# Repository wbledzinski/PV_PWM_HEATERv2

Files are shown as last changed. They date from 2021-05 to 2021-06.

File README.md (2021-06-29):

# PV_PWM_HEATERv2
photovoltaic MPPT electric heater controller for heat buffer

## MPPT PWM 400V DC 10A heater controller board

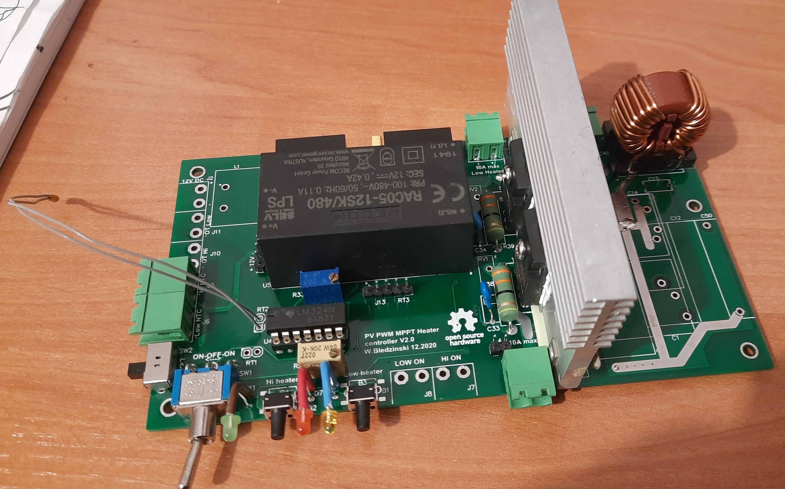
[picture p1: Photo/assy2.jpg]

Second version of controller

###  ◾ About this project
Project was developed to maximize energy transfer from 3,5kW solar array into heaters installed in 1000l heat buffer.
You can find similar systems already in market, ready to purchase but no one had power that I needed.
Below you can find schematic of the idea how to store small, medium and big amounts of heat generated by DC current from solar array.

###  ◾ Overall concept - how to store 50kWh of energy in form of heat and why
Some time ago I built heat buffer to collect and store heat from available heat sources. Basic concept was to store heat from buring coal or wood (furnace is more efficient working at full power and produces less air pollutants). Electric heaters were installed "just in case" of further development. Heat is used for heating whole house and tap water as well.

Using PV array to produce heat sounds as not particularly bright idea: during wintertime there is no enough sunny weather to produce reasonable amount of energy from PV array to heat whole building (I live at 50* latitude in Europe).
But summertime (autumn and spring usually as well) makes big difference. 5 people cannot use all heat produced by this system.
So during summertime I use generated heat to fill small pool (500liters) for kids - already with warm water, no waiting to warm-up, fresh and hot water in pool every day.
Also heat buffer is large enough that hot water stored from two sunny days lasts for next two days even if they are cloudy.
schematic of that system below

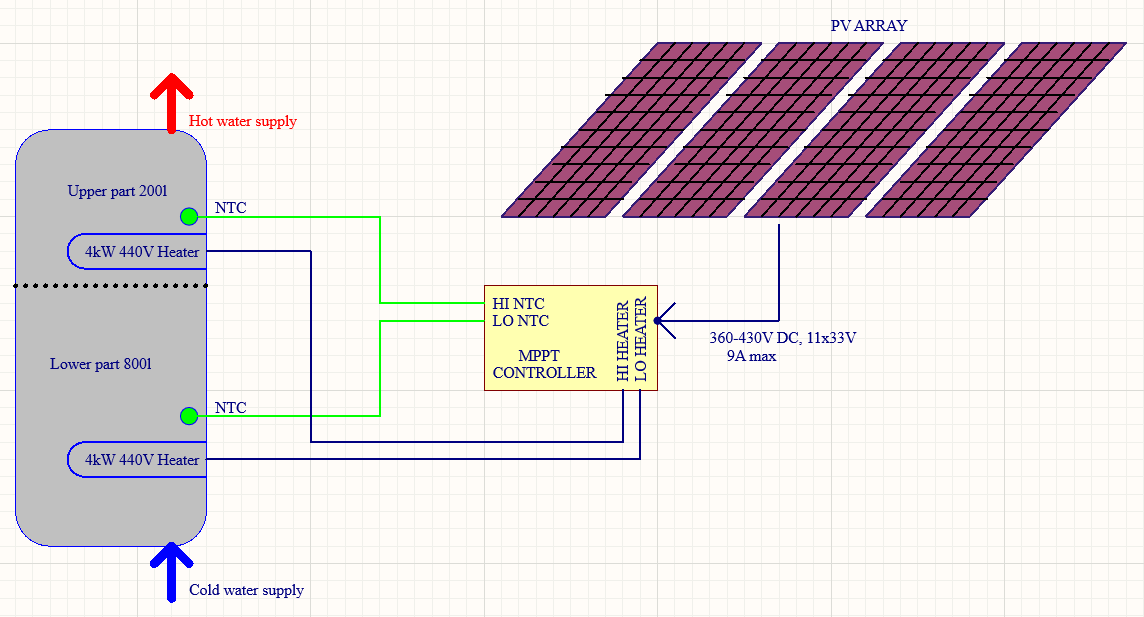
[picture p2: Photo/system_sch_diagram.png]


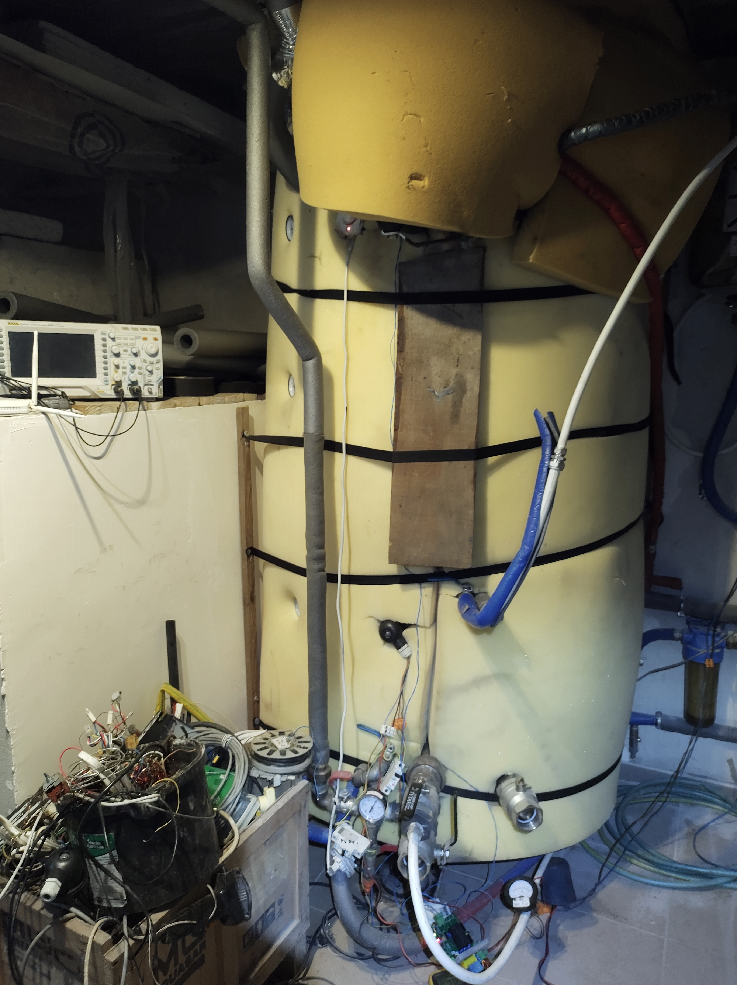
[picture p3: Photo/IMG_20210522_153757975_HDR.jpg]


real photo of heat buffer

###  ◾ Why I used two heaters
1. To make use of layered heat tank. If particular day is not excessively sunny then controller heats only upper part of the tank (200l of water).
2. if there is clear sky, long sunny day AND there is already hot water in upper part of the tank then controller stops using upper heater and drives only the lower heater
3. one heater (in form of serially connected two 230V 2kW heaters) can't put anough load to solar array. you need a bit more load so: in full sunshine upper heater works with 100% and lower just about 20% of possible load - only then you can mantain maximum power point (in my case somewhere ~360V DC).

###  ◾ MPPT Controller theory of operation ('MPPT' tracking)
Generally speaking you can't connect heaters directly as a load into solar array. Or at least you can, but you will loose lot of energy.
You can find lot of explanations why this is so.
So you have to track maximum power point of your solar array, controllers that can do that are called MPPT and they are usually very expensive (although there is reason for that). I thought that there is no sense of converting DC energy into AC energy to power simple electric heater. So after small research ([see sample project from youtube]( https://www.youtube.com/watch?v=ciyA7mSo7IY)) i decided to built my own controller board.

**Maximum-Power-Point-Tracking**
To be clear: controller doesn't follow power point of solar array, it follows voltage. I added temperature correction (about 10V) that depends on temperature of NTC.
In my case this NTC measures ambient temperature. To properly follow MPP of PV array you should measure temperature of PV array not ambient.
in my opinion this solution is good enough but not perfect.
Perfect solution should be based on microcontroller that calculates actual power not just voltage.

**General idea is to use RC circuit to oscillate around MPP of solar array.**
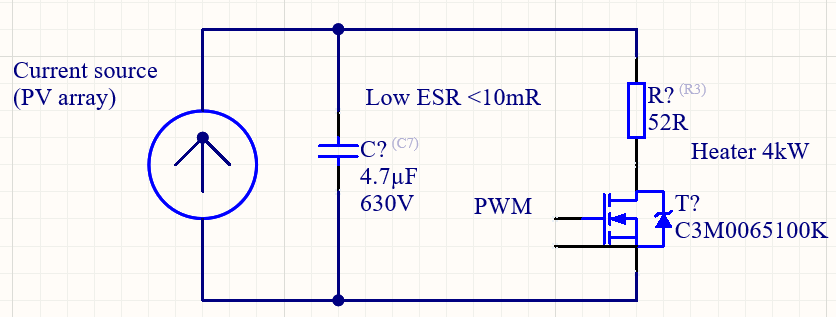
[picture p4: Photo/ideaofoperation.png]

It is basic idea of RC oscillator. The only difference is that PV array of that size produces 360VDC (disconnected even 440VDC) and almost 10A continuosly: RC oscillators usually have much less power.

So some simulations and futher research was needed.
Below you can find LTSpice simulation results for partially cloudy day (50% of PWM), just for simulation I set MPP at 330V.
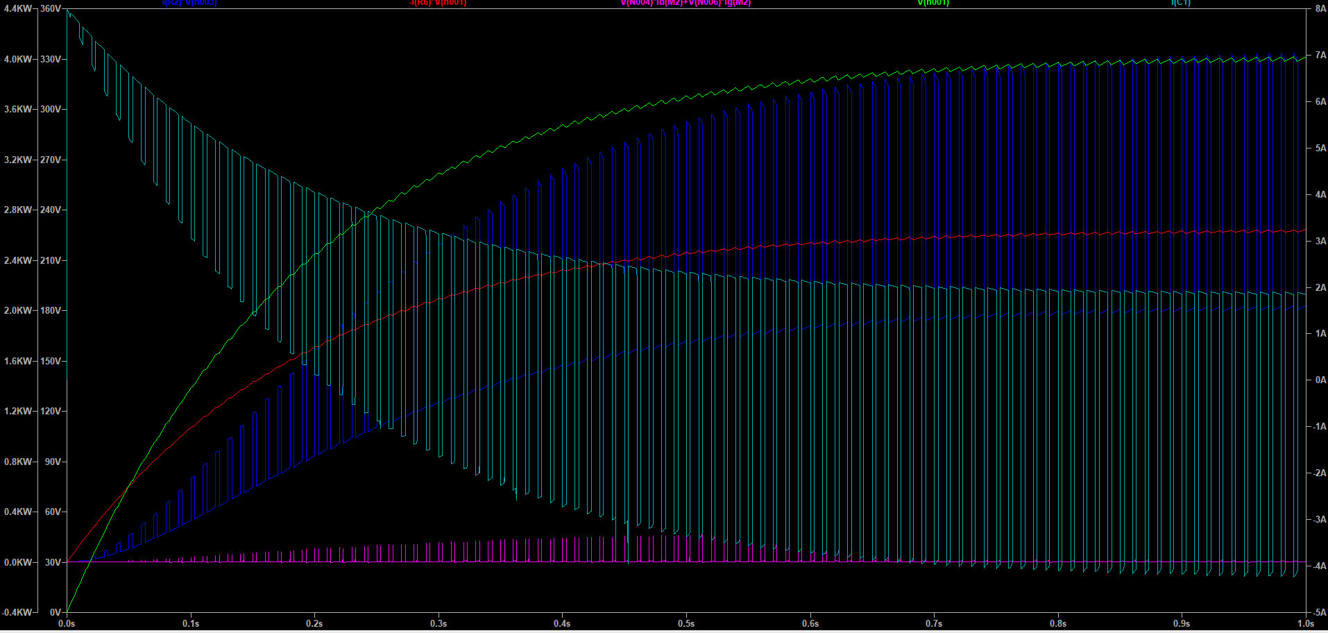
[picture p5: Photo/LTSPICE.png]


green curve shows oscillations around MPP at 360VDC (actually it is set by potentiometer on the board).
Hysteresis at 360V MPP was set to 5V.
transistor connects the load (heater) and main capacitor acts as short-term energy source.
Capacitor must withstand current of 10A so special low ESR capacitor is needed (4.7uF 630V DC 6mR from EPCOS)
transistor must be good as well: any inductance produces voltage spikes that doubles overall voltage between drain and source. And even driving mosfet with 100% PWM makes thing hard because 10A current produces conductivity loses.

Picture below shows Drain-Source voltage of SiC transistor (Infineon's IMZ120R030M1HXKSA1).
schema

###  ◾ Actual idea of operation for this controller
Critical components are big cap and two power transistors. I tested Infineons SiC parts IMZ120R030M1HXKSA1 and IMZ120R045M1XKSA1 toogether with EPCOS B32674D6475K000 4u7 and B32774D8126K000 12uF (don't be suprised, big cap value gives acoustic noise due to low frequency of operation BUT low frequency generates less commuting loses).
Actually I don't care about noise generated by caps, my controller and heat tank is installed in basement. So I've hosen lower frequency to decrease switching loses.

#### voltage set point

high priority heater (upper one) has circuit with mean voltage operation set point around 350VDC.

the lower priority heater has voltage set-point 10V higher ~360V DC.

In case of partial sun/low energy producing PV array (due to low sun early in the morning, or due to cluds) controller uses only high pririty heater (upper in the heat buffer) and operates around 350V DC.

When PV array produces more than 2,5kW of power one heater (~52ohm) cann't operate at MPP for PV array - voltage raises even to 380VDC. No problem for the heater but operating at that high voltage is out of MPP for my arrray.
So there comes into action second heater with second (10V higher) voltage set-point:
upper heater is driven 100% PWM, and second (physically lower in heat buffer) heater is driven with PWM that enables PV to operate at 360V DC.
PV array can then operate at voltage point close to MPP.

if there is already hot water in the tank AND sunny weather continues the controller stops driving both heaters and gives signal thru optocouplers: you can use that to control classic grid inverter to generate electricity and return that to the grid. But heaters have priority in that case and energy can be sent to grid only when there is no need for generatin more heat.

###  ◾ Safety of electric and hydraulic systems
there is no strict SIL biult-in in that controller. I would recommend some double security to preven fire (due to overheating of electronics itself) or to prefent pressure biuldup in heater tank (in case of NTC failure).
My system has only one level of safety for every critical component.
1. thermostat for transistor heatsink - over 100C it disconnects voltage sensing - controller stops operation
2. 2x NTC at heat buffer - to preven overheating/boiling water. But if NTC fails due to internal malfunction OR due to lack of sufficient thermal connection to tank OR if there is short on power transistor *there is no other security measure to preven overheating
3. to prevent pressure build-up (in case of NTC failure or transistor malfunction ) that tank itself has an overflow port - it allows to escape if there is any excessive prese, no matter the cause: from excessive water level or from steam
4. to prevent any burn due to very hot tap vater I installed hydraulic thermostat valve at buffer output, it is set to 55C
5. to prevent any bacteria to growth you can't store 1000l of tap water. Buffer has built-in heat exchanger in form of spiral copper pipe (copper itself is bacteriostatic), 20mm diameter, 50m long. Heat exchanger capacity is about 10liters. 1000l of water accumulates heat and never will be used for consumtion directly in any form.

temperature limits for heaters are set (with hysteresis):
testing original (designed) resistor values:
switch position Low Temperature

NTC L: 1,5k - 1,9k	(73*C-66*C)

NTC H: 3,1k-4,0k	(53*C-47*C)

switch position High Temperature

NTC L: 1,2k-1,3k	(80*C-76*C)

NTC H: 1,8k-2,1k	(68*C-59*C)

###  ◾ Main components
Sorry for choosen language but this is the exact part number that I used.
heater
https://www.egniazdka.pl/grzalka-do-bojlera-z-kolpakiem-eliko-grbk-3x2000w-u-64-p-1829.html
low ESR capacitor
https://pl.farnell.com/epcos/b32674d6475k000/cap-4-7-f-630v-10-pp/dp/2728560
SiC transistor
https://pl.farnell.com/infineon/imz120r030m1hxksa1/mosfet-n-ch-1-2kv-56a-175deg-c/dp/3223684
DCDC converter
https://pl.farnell.com/recom-power/rac10-12sk-277/power-supply-ac-dc-12v-0-84a/dp/2822840

### ◾ Similar solution
https://www.ebay.de/itm/Hezspirale-Heizelement-Heizstab-6000-W-3x2000W-230-V-Abdeckung-/221984855525
here similar solution, but with only one channel , smaller voltage (for smaller PV array)

###  ◾ BOM cost
I had to build two versions + during testing I burned one transistor (due to DC arc) so this was not completely cheap project.
but properly assembled one piece of that board should cost you about:
* PCB JLCPCB $20
* main transistors, capacitor, DCDC converter other major components about $100

###  ◾ Assembly
Only one uncommon thing about assembly. All SMD components were soldered using soldering paste and "T962 Infrared SMD BGA IC Heater". smallest component is of 0603 size and I tested 3D printed stencil - it works pretty good for components of that size. Smallest IC is SOT23-5 and there was no need for improving soldering point manually.
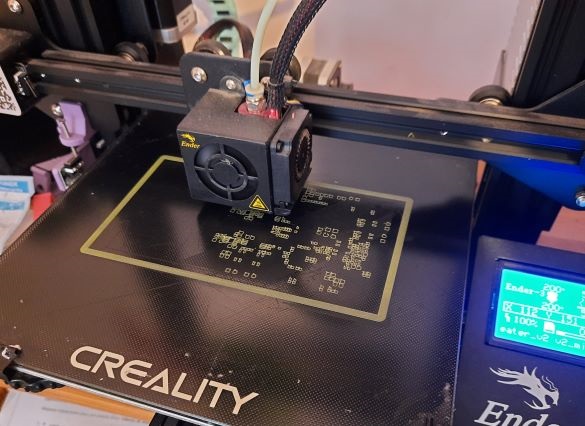
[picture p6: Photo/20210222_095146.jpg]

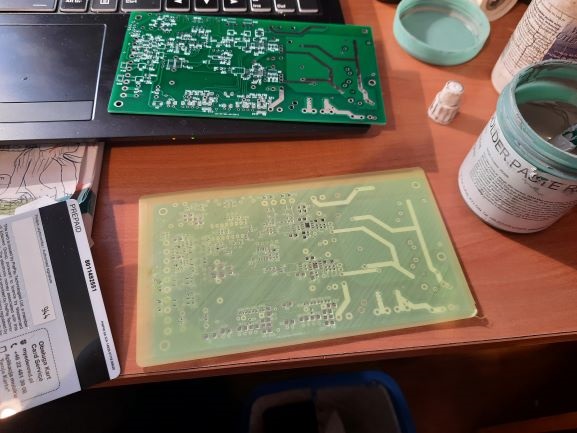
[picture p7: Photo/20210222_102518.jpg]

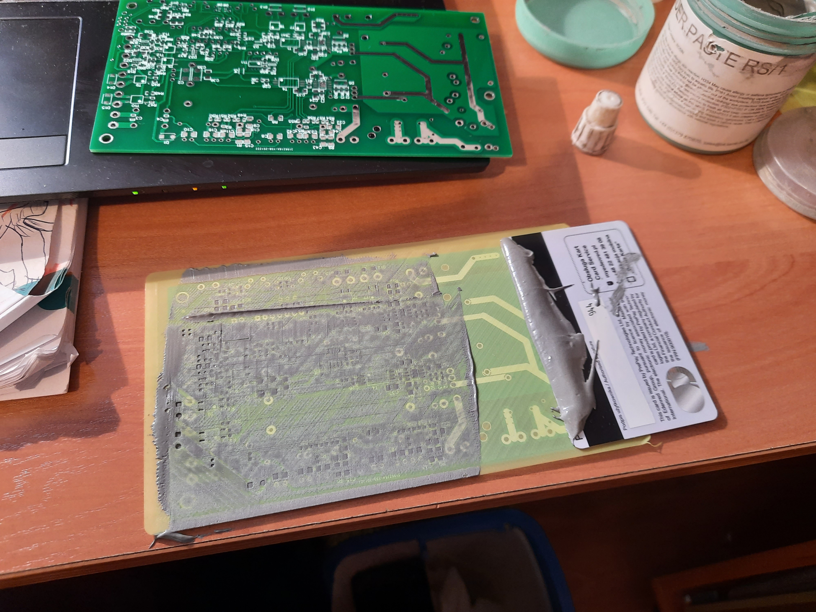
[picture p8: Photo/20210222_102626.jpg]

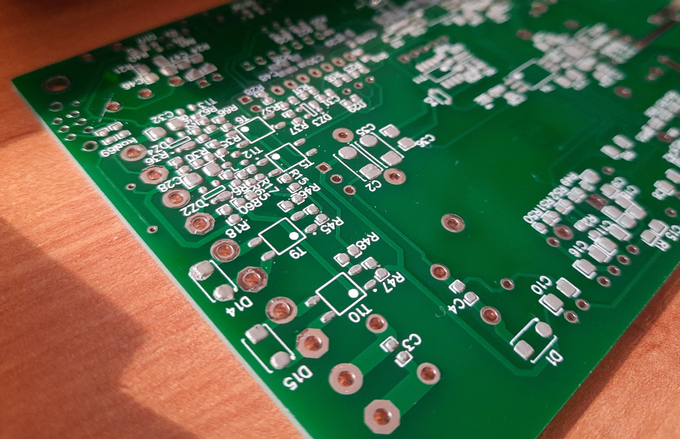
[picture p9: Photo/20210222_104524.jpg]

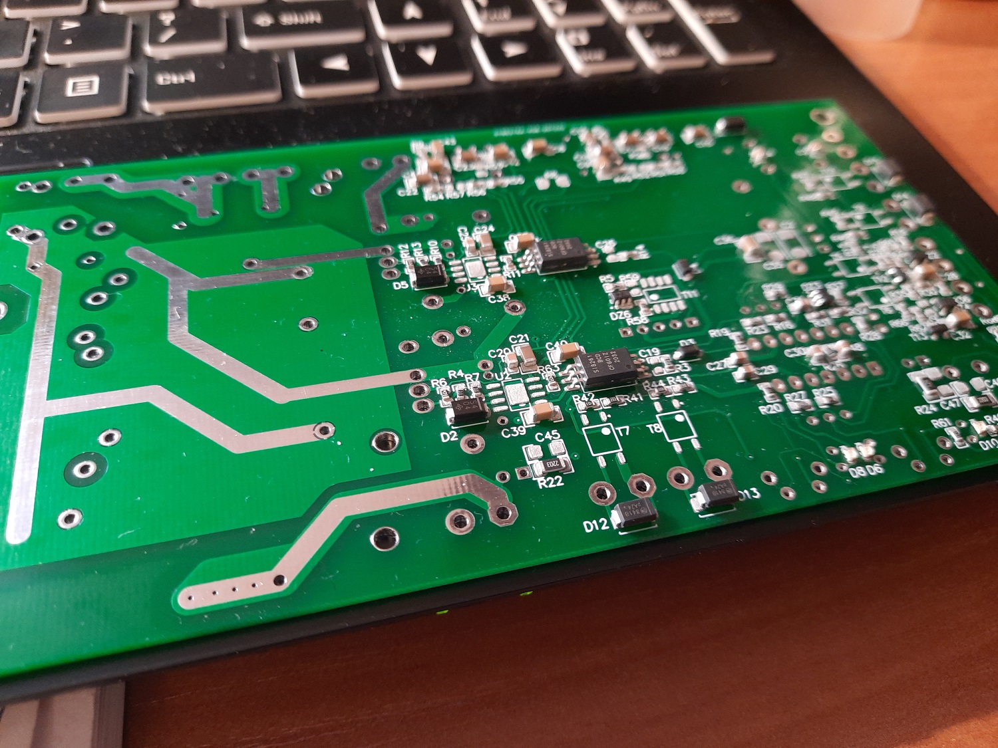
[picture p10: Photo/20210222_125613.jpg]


###  ◾ Launching
Durnig launching you have to set voltage operating points near maximum power point of your PV array - by setting both potentiometers.
I've checked temperatures during operation, picture below shows board temperatures during hot sunny day, current from PV array ~8A, PV temperature ~40degC.
Power transistors (natural convection) has ~50degC.
During sunny but cold day when PV array is cold (say 0degC) current reaches even 11A (more than nominal specified by manufacturer of my panels (320W longi).

Actually I had no issues during launching whatsoever.

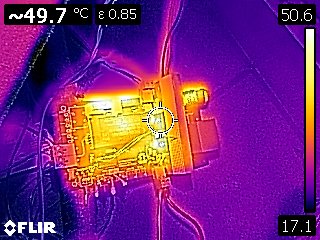
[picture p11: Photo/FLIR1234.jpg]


the only damage to first version (100% my fault, just don't short drain and source during operation, it will create an arc)

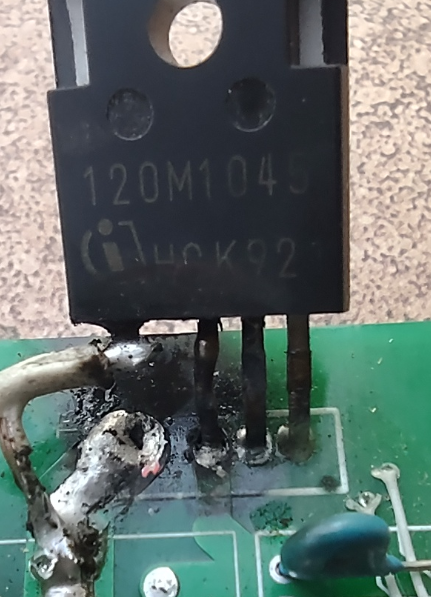
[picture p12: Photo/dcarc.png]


###  ◾ Summary
I hope you enjoy this project. I'm sure that furher development should use microcontroller to properly control MPPT of solar array.
For me most important part is that I developed high voltage power stage of that controller, further development should consider change of SiC driver for something more covienient, e.g. NCP51705; move from op-amp logic for microcontroller. It seems less stresfull during launch (leaving that installation for a week without supervision really maked me stressed, I imagined firefighters in place several times, even hearing nearby sirene made me anxious).
As for now it works without any flaws.

Do not hesitate to reach me in case of any questions,
br,

Wojtek

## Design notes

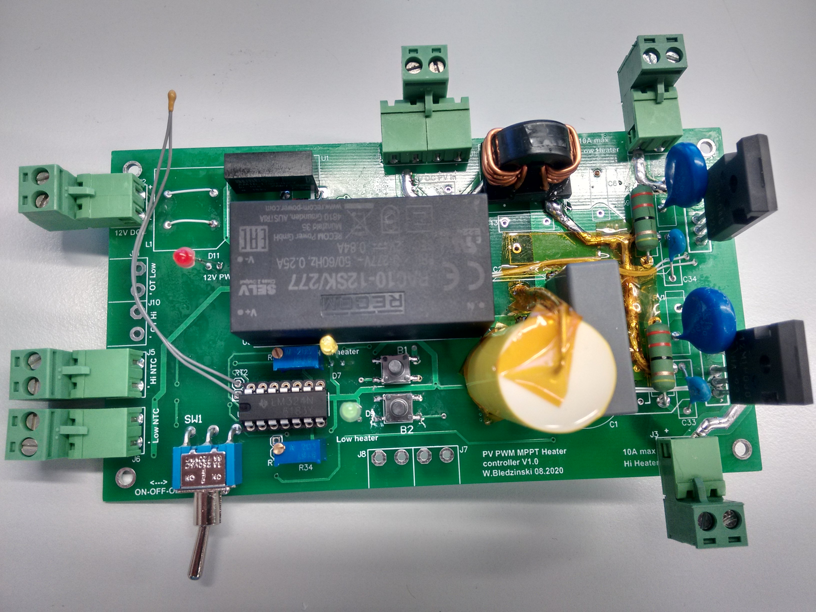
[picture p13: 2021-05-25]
Photo/assy1.jpg

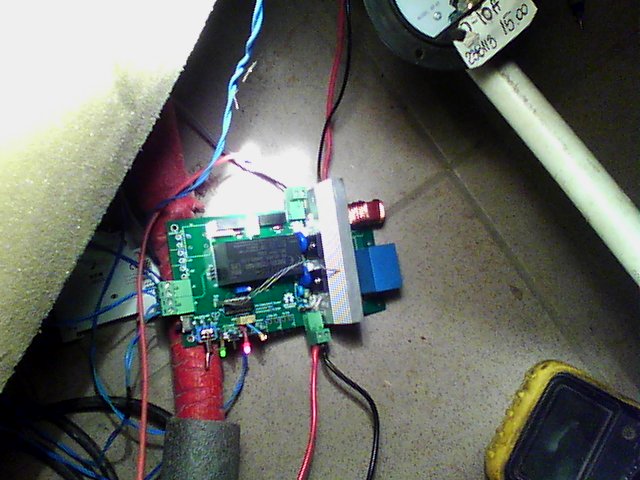
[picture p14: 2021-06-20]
Photo/FLIR1235.jpg

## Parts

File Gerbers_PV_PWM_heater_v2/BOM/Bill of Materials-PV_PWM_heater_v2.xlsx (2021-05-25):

Comment | Description | Designator | Footprint | LibRef | LogicalDesignator | Manufacturer | Manufacturer 1 | Manufacturer 2 | Manufacturer Part Number | Manufacturer Part Number 1 | Manufacturer Part Number 2 | PartType | Price10 | Price1k | Pricing | Quantity | Supplier | Supplier 1 | Supplier 2 | Supplier Currency 1 | Supplier Currency 2 | Supplier Order Qty 1 | Supplier Order Qty 2 | Supplier Part Number | Supplier Part Number 1 | Supplier Part Number 2 | Supplier Stock 1 | Supplier Stock 2 | Supplier Subtotal 1 | Supplier Subtotal 2 | Supplier Unit Price 1 | Supplier Unit Price 2 | Value | Layer
SW_TACTSWITCH6x6 | SE PUSHBUTTON | B1, B2 | SW_TACT6x6 | SW_TACTSWITCH6x6 | B1, B2 | ITT C&K | Loading... |  | PTS645SK50SMTR92LFS | Loading... |  | SW_TACTSWITCH6x6 |  |  |  | 2 |  | TME |  | Loading... |  |  |  |  | PTS645SK50SMTR92 |  |  |  |  |  | $0.1402 |  |  | Top
SW_TACTSWITCH6x6_RA_THT | SE PUSHBUTTON | B3, B4 | SW_TACT6x6_RA | SW_TACTSWITCH6x6_RA_THT | B3, B4 | TE | Loading... |  | 1-1825027-1 | Loading... |  | SW_TACTSWITCH6x6_RA_THT |  |  |  | 2 |  | TME |  | Loading... |  |  |  |  | 1-1825027-1 |  |  |  |  |  | $0.1402 |  |  | Top
12u/700VAC | poliester capacitor THT | C1, C12, C50 | CAP_THT27.5mm | CAP_B_12u_700_THT | C1, C12, C50 | EPCOS |  |  | B32774D8126K000 |  |  | 12u/700VAC | 8 | 6 |  | 3 | TME | FARNELL |  |  |  |  |  |  |  |  |  |  |  |  |  |  | 12u/700VAC | Top
47u/16 | ESR 1.2R 10VDC at 125stC | C2, C35 | TAJC | CAP_E_47u_16_TAJC | C2, C35 | KEMET | Loading... |  | T491C476K016AT | Loading... |  | 47u/16 | 0.4 | 0.3 |  | 2 | TME | Farnell |  | Loading... |  |  |  | T491C476K016AT | 1457486 |  |  |  |  |  | Loading... |  | 47u/16 | Bottom
100n/50 | X7R chip capacitor | C3, C4, C20, C25, C27, C29, C30, C31, C48 | CAP_0603 | CAP_B_100n_50_0603_X7R | C3, C4, C20, C25, C27, C29, C30, C31, C48 | SAMSUNG |  |  | CL10B104KB8NNNC |  |  | 100n/50 | 0.1 | 0.006 |  | 9 | TME |  |  |  |  |  |  | CL10B104KB8NNNC |  |  |  |  |  |  |  |  | 100n/50 | Bottom
1u/850VDC | poliester capacitor THT, esr 5mR, 9A/140A pk | C5 | CAP_AXIAL50X20mm | CAP_B_1u_850_THT | C5 | KEMET | Loading... |  | C4GAMUC4100AA1J | Loading... |  | 1u/850VDC | 3.8 | 2.44 |  | 1 | TME | FARNELL |  | Loading... |  |  |  | C4GAMUC4100AA1J | 2808972 |  |  |  |  |  | Loading... |  | 1u/850VDC | Top
3u3/600VDC | poliester capacitor THT, esr 2.4mR, 25A/342A pk; 350VAC | C6 | CAP_THT27.5X22mm | CAP_B_3u3_600_THT | C6 | KEMET | Loading... |  | C4ATHBW4330A3GJ | Loading... |  | 3u3/600VDC | 6.18 | 4.02 |  | 1 | TME | FARNELL |  | Loading... |  |  |  | C4ATHBW4330A3GJ | 2664828 |  |  |  |  |  | Loading... |  | 3u3/600VDC | Top
2n2/250VAC X1,Y2 | poliester capacitor THT X1 Y2, Y5V | C7, C13, C49 | CAP_THT7.5mm | CAP_B_2n2_250_X1Y2_THT | C7, C13, C49 |  |  |  | CY2V-2N2 |  |  | 2n2/250VAC X1,Y2 | 0.3 | 0.25 |  | 3 | TME |  |  |  |  |  |  | CY2V-2N2 |  |  |  |  |  |  |  |  | 2n2/250VAC X1,Y2 | Top
1u/50 | X7R chip capacitor | C8, C9, C10, C11, C15, C16, C18, C21, C22, C23, C24, C28, C32, C36, C37, C38, C39, C40, C42, C43, C44 | CAP_1206 | CAP_B_1u_50_1206_X7R | C8, C9, C10, C11, C15, C16, C18, C21, C22, C23, C24, C28, C32, C36, C37, C38, C39, C40, C42, C43, C44 | TDK | Loading... |  | C3216X7R1H105K160AB | Loading... |  | 1u/50 | 0.24 | 0.044 |  | 21 | TME | FARNELL |  | Loading... |  |  |  | 12065C105KAT2A | 1857302 |  |  |  |  |  | Loading... |  | 1u/50 | Bottom
5u6/500VDC | poliester capacitor THT, esr 13mR, | C14 | CAP_THT27.5X11mm | CAP_B_5u6_500_THT | C14 | KEMET | Loading... |  | C4AQLBU4560A1WK | Loading... |  | 5u6/500VDC | 2 | 0.8 |  | 1 | TME | FARNELL |  | Loading... |  |  |  | C4AQLBU4560A1WK | 2846425 |  |  |  |  |  | Loading... |  | 5u6/500VDC | Top
2n2/250VAC | poliester capacitor THT Y2 | C17, C41 | CAP_THT10mm | CAP_B_2n2_250_THT | C17, C41 | WIMA |  |  | MPY20W1220FA00MSSD |  |  | 2n2/250VAC | 0.3 | 0.25 |  | 2 | TME |  |  |  |  |  |  | MP3-Y2-2N2 |  |  |  |  |  |  |  |  | 2n2/250VAC | Top
DNP | X7R chip capacitor | C19, C26 | CAP_0603 | CAP_B_100n_50_0603_X7R | C19, C26 | SAMSUNG |  |  | CL10B104KB8NNNC |  |  | DNP | 0.1 | 0.006 |  | 2 | TME |  |  |  |  |  |  | CL10B104KB8NNNC |  |  |  |  |  |  |  |  | 100n/50 | Bottom
220p | poliester capacitor THT X1 Y2, Y5V | C33, C34 | CAP_THT7.5mm | CAP_B_2n2_250_X1Y2_THT | C33, C34 |  |  |  | CY2V-2N2 |  |  | 220p | 0.3 | 0.25 |  | 2 | TME |  |  |  |  |  |  | CY2V-2N2 |  |  |  |  |  |  |  |  | 2n2/250VAC X1,Y2 | Top
1n/200V | C0G chip capacitor | C45, C46, C47 | CAP_1206 | CAP_B_100n_50_1206_C0G | C45, C46, C47 | TDK | Loading... |  | CGA5L2C0G1H104J160AA | Loading... |  | 1n/200V | 0.7 | 0.16 |  | 3 | FARNELL | FARNELL |  | Loading... |  |  |  | 2211074 | 2211074 |  |  |  |  |  | Loading... |  | 1n/200V | Bottom
Shottky 2A/20V | Shottky Diode 0,5V @ 2A SMA 200pF | D1 | SMA_DO-214AC | D_2A_20_B220A | D1 | DIODES | Loading... |  | B220A-13-F | Loading... |  | Shottky 2A/20V | 0.15 | 0.06 |  | 1 | AVNET | FARNELL |  | Loading... |  |  |  | B220-13-F | 1858604 |  |  |  |  |  | Loading... |  | Shottky 2A/20V | Bottom
SS14-E3/61T |  | D2, D5 | SMA_DO-214AC | D_SS14 | D2, D5 | Vishay Semiconductors | Loading... |  | SS14-E3/61T | Loading... |  | SS14-E3/61T |  |  |  | 2 |  | TME |  | Loading... |  |  |  |  | SS14-E3/61T |  |  |  |  |  | $0.26376 |  |  | Bottom
Shottky 0.5A/30V MBR0530T1G | Shottky Diode trr 4ns 0,43V @ 0.5A 0.37V@0.1A | D3, D4 | SOD_123 | D_0.5A_30_MBR0530T1G | D3, D4 | ON | Loading... |  | MBR0530T1G | Loading... |  | Shottky 0.5A/30V MBR0530T1G | 0.38 | 0.06 |  | 2 | TME | FARNELL |  | Loading... |  |  |  | MBR0530T1G | 1431036 |  |  |  |  |  | Loading... |  | Shottky 0.5A/30V MBR0530T1G | Bottom
Green LED KP-1608SGC | Diode LED SMD 2.2V @ 20mA 15mcd | D6, D8, D10 | LED_0603_GREEN | D_LED_0603_GREEN | D6, D8, D10 | KINGBRIGHT | Loading... |  | KP-1608SGC | Loading... |  | Green LED KP-1608SGC | 0.05 | 0.03 |  | 3 | TME | Farnell |  | Loading... |  |  |  | KP-1608SGC | 8529833 |  |  |  |  |  | Loading... |  | Green LED KP-1608SGC | Bottom
Red LED 3mm THT | Diode LED THT | D7, D9, D11 | LED_3MM | D_LED3_THT_RED | D7, D9, D11 | KINGBRIGHT | Loading... |  | L-934SRC-E | Loading... |  | Red LED 3mm THT | 0.12 | 0.1 |  | 3 | TME | Farnell |  | Loading... |  |  |  | L-934SRC/E | 1142524 |  |  |  |  |  | Loading... |  | Red LED 3mm THT | Top
39 | transil jednostronny | D12, D13, D14, D15 | SMA_DO-214AC | D_TR_UNI_SMA6TY_39V | D12, D13, D14, D15 | STM | Loading... |  | SMA6T39AY | Loading... |  | 39 | 1 | 0.4 |  | 4 | ARROW | Digi-key |  | Loading... |  |  |  | SMA6T39AY | 497-10949-2-ND |  |  |  |  |  | Loading... |  | Transil_U_600W | Bottom
3V 1W |  | DZ1, DZ5 | D_DO-15_DO-204AC | D_1W_20_ZENER | DZ1, DZ5 |  | Loading... |  |  | Loading... |  | 3V 1W | 0.08 | 0.04 |  | 2 | TME | TME |  | Loading... |  |  |  | 1.3W-3V | 1.3W-3V |  |  |  |  |  | Loading... |  | 3V 1W | Top
TS431 0,5% 1.24V | 0,5% 1.24V vref | DZ2, DZ3, DZ4, DZ6 | SOT23_5_DBV_R-PDSO-G5 | D_TS431BILT | DZ2, DZ3, DZ4, DZ6 | STMicroelectronics | Supplier disabled |  | TS431BILT | Supplier disabled |  | TS431 0,5% 1.24V |  |  | 6000=0.2339, 12000=0.2229, 18000=0.2129, 30000=0.2029, 60000=0.1989 (USD) | 4 | TME | Avnet |  | Supplier disabled |  |  |  |  | TS431BILT |  |  |  |  |  | Supplier disabled |  | TS431 0,5% 1.24V | Bottom
5.08 TB H | THT 5,08mm, WE 691312510002, NINIGI TBG-5-KB-2P/GN, MLX 395320002 | J1, J2, J3, J4, J5, J6, J7, J8, J9, J10, J11 | CON_1x2_5.08TBRA | CON_1x2_TB_5.08H | J1, J2, J3, J4, J5, J6, J7, J8, J9, J10, J11 | Molex | Loading... (https://octopart-clicks.com/click/altium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) | Loading... (https://octopart-clicks.com/click/altium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) | 39532-0002 | Loading... (https://octopart-clicks.com/click/altium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) | Loading... (https://octopart-clicks.com/click/altium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) | 5.08 TB H |  |  |  | 11 |  | Mouser | TME | Loading... | Loading... |  |  |  | 710-691312510002 (https://octopart-clicks.com/click/altium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) | TBG-5-KB-2P/GN (https://octopart-clicks.com/click/altium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) |  |  |  |  | $0.8421 |  |  | Top
1x3p 2.54mm GP | THT 2,54 goldpin | J12, J13 | CON_PIN1x3_THT | CON_1x3_GP_THT | J12, J13 | TME | Loading... |  | ZL201-03G | Loading... |  | 1x3p 2.54mm GP | 0.15 | 0.1 |  | 2 | TME | digi-key |  | Loading... |  |  |  | ZL201-03G | WM8073-ND |  |  |  |  |  | Loading... |  | 1x3p 2.54mm GP | Top
1x2p 2.54mm GP | THT 2,54 goldpin | J14 | CON_PIN1x2_THT | CON_1x2_GP_THT | J14 | TME | Loading... |  | ZL201-02G | Loading... |  | 1x2p 2.54mm GP | 0.15 | 0.1 |  | 1 | TME | digi-key |  | Loading... |  |  |  | ZL201-02G | WM8072-ND |  |  |  |  |  | Loading... |  | 1x2p 2.54mm GP | Top
2,2mH 4A 744823422 | 2x2,2mH 40dB 1MHz 4A 250VAC Rdc=2x0,03 SRF1MHz | L1, L2 | IND_WE-CMB-M | IND_WE-CMB_2.2mH_4A_THT | L1, L2 | WE | Loading... |  | 744823422 | Loading... |  | 2,2mH 4A 744823422 | 5 | 4.5 |  | 2 | RS-Components | Digi-Key |  | Loading... |  |  |  | 489-0273 | 732-1445-ND |  |  |  |  |  | Loading... |  | 2,2mH 4A 744823422 | Top
2,2mH 4A 744824101 | 2x2,2mH 30dB 1MHz 10A 250VAC Rdc=2x0,007 SRF1MHz | L3 | IND_WE-CMB-l | IND_WE-CMB_2.2mH_10A_THT | L3 | WE | Loading... |  | 744824101 | Loading... |  | 2,2mH 4A 744824101 | 5 | 4.5 |  | 1 | RS-Components | Digi-Key |  | Loading... |  |  |  |  | 732-1449-ND |  |  |  |  |  | Loading... |  | 2,2mH 4A 744824101 | Top
2k | Resistor 1206 5% 0,25W | R1, R9 | RES_1206 | RES_510R_5p_1206 | R1, R9 | YAGEO | Loading... |  | RC1206JR-07510R | Loading... |  | 2k | 0.009 | 0.004 |  | 2 | TME | Farnell |  | Loading... |  |  |  | RC1206JR-07510R | 2057829 |  |  |  |  |  | Loading... |  | 510R 5% | Bottom
DNP | 0603 ,1W, 0603 ,1W, 0603 ,1W, 0603 ,1W, Resistor 0603 5% 0,1W, Resistor 0603 5% 0,1W, Resistor 0603 5% 0,1W | R2, R52, R53, R57, R59, R60, R62 | RES_0603 | RES_0R_5p_0603, RES_0R_5p_0603, RES_0R_5p_0603, RES_0R_5p_0603, RES_3k_5p_0603, RES_3k_5p_0603, RES_3k_5p_0603 | R2, R52, R53, R57, R59, R60, R62 | YAGEO | Loading... |  | RC0603JR-070RL, RC0603JR-070RL, RC0603JR-070RL, RC0603JR-070RL, [NoValue], [NoValue], [NoValue] | Loading... |  | DNP | 0.09, 0.09, 0.09, 0.09, 0.01, 0.01, 0.01 | 0.003 |  | 7 | TME | TME |  | Loading... |  |  |  | RC0603JR-070R, RC0603JR-070R, RC0603JR-070R, RC0603JR-070R, SMD0603-3K, SMD0603-3K, SMD0603-3K | RC0603JR-070R, RC0603JR-070R, RC0603JR-070R, RC0603JR-070R, SMD0603-3K, SMD0603-3K, SMD0603-3K |  |  |  |  |  | Loading... |  | 0R 5%, 0R 5%, 0R 5%, 0R 5%, 3k 5%, 3k 5%, 3k 5% | Bottom
2k2 | Resistor 0603 5% 0,1W | R3, R14, R15, R30, R41, R43, R46, R48 | RES_0603 | RES_3k_5p_0603 | R3, R14, R15, R30, R41, R43, R46, R48 | YAGEO | Loading... |  |  | Loading... |  | 2k2 | 0.01 | 0.003 |  | 8 | TME | TME |  | Loading... |  |  |  | SMD0603-3K | SMD0603-3K |  |  |  |  |  | Loading... |  | 2k2, 2k2, 3k 5%, 3k 5%, 3k 5%, 3k 5%, 3k 5%, 3k 5% | Bottom
10R 5% | Resistor 0603 5% 0,1W | R4, R7, R10, R13 | RES_0603 | RES_10R_5p_0603 | R4, R7, R10, R13 | YAGEO | Loading... |  |  | Loading... |  | 10R 5% | 0.01 | 0.003 |  | 4 | TME | TME |  | Loading... |  |  |  | SMD0603-10R | SMD0603-10R |  |  |  |  |  | Loading... |  | 10R 5% | Bottom
240 | Resistor 0603 5% 0,1W | R5 | RES_0603 | RES_10R_5p_0603 | R5 | YAGEO | Loading... |  |  | Loading... |  | 240 | 0.01 | 0.003 |  | 1 | TME | TME |  | Loading... |  |  |  | SMD0603-10R | SMD0603-10R |  |  |  |  |  | Loading... |  | 10R 5% | Bottom
47k 5% | Resistor 0603 5% 0,1W | R6, R11, R12, R63 | RES_0603 | RES_47k_5p_0603 | R6, R11, R12, R63 | YAGEO | Loading... |  |  | Loading... |  | 47k 5% | 0.01 | 0.003 |  | 4 | TME | TME |  | Loading... |  |  |  | SMD0603-47K | SMD0603-47K |  |  |  |  |  | Loading... |  | 47k 5% | Bottom
DNP | Resistor 1206 5% 0,25W | R8 | RES_1206 | RES_0R_5p_1206 | R8 | ROYAL OHM | Loading... |  | 1206S4J0000T5E | Loading... |  | DNP | 0.3 | 0.24 |  | 1 | TME | Farnell |  | Loading... |  |  |  | SMD1206-0R | 9336974 |  |  |  |  |  | Loading... |  | 0R 5% | Bottom
1k | Resistor 0603 5% 0,1W | R16, R19, R20, R25, R40, R65, R66 | RES_0603 | RES_3k_5p_0603 | R16, R19, R20, R25, R40, R65, R66 | YAGEO | Loading... |  |  | Loading... |  | 1k | 0.01 | 0.003 |  | 7 | TME | TME |  | Loading... |  |  |  | SMD0603-3K | SMD0603-3K |  |  |  |  |  | Loading... |  | 3k 5% | Bottom
10k 5% | Resistor 0603 5% 0,1W | R17, R31, R35, R36, R42, R44, R45, R47, R58, R64, R67 | RES_0603 | RES_10k_5p_0603 | R17, R31, R35, R36, R42, R44, R45, R47, R58, R64, R67 |  |  |  |  |  |  | 10k 5% | 0.01 | 0.003 |  | 11 |  |  |  |  |  |  |  |  |  |  |  |  |  |  |  |  | 10k 5% | Bottom
15k | Resistor 0603 5% 0,1W | R18 | RES_0603 | RES_10k_5p_0603 | R18 |  |  |  |  |  |  | 15k | 0.01 | 0.003 |  | 1 |  |  |  |  |  |  |  |  |  |  |  |  |  |  |  |  | 10k 5% | Bottom
220k | Resistor 1206 5% 0,25W | R21, R22 | RES_1206 | RES_510R_5p_1206 | R21, R22 | YAGEO | Loading... |  | RC1206JR-07510R | Loading... |  | 220k | 0.009 | 0.004 |  | 2 | TME | Farnell |  | Loading... |  |  |  | RC1206JR-07510R | 2057829 |  |  |  |  |  | Loading... |  | 510R 5% | Bottom
2M | Resistor 0603 5% 0,1W | R23, R27 | RES_0603 | RES_3k_5p_0603 | R23, R27 | YAGEO | Loading... |  |  | Loading... |  | 2M | 0.01 | 0.003 |  | 2 | TME | TME |  | Loading... |  |  |  | SMD0603-3K | SMD0603-3K |  |  |  |  |  | Loading... |  | 3k 5% | Bottom
120k | Resistor 1206 5% 0,25W | R24 | RES_1206 | RES_510R_5p_1206 | R24 | YAGEO | Loading... |  | RC1206JR-07510R | Loading... |  | 120k | 0.009 | 0.004 |  | 1 | TME | Farnell |  | Loading... |  |  |  | RC1206JR-07510R | 2057829 |  |  |  |  |  | Loading... |  | 510R 5% | Bottom
2k | Resistor 0603 5% 0,1W | R26, R29 | RES_0603 | RES_3k_5p_0603 | R26, R29 | YAGEO | Loading... |  |  | Loading... |  | 2k | 0.01 | 0.003 |  | 2 | TME | TME |  | Loading... |  |  |  | SMD0603-3K | SMD0603-3K |  |  |  |  |  | Loading... |  | 3k 5% | Bottom
5.1k 5% | Resistor 0603 5% 0,1W | R28, R37 | RES_0603 | RES_5.1k_5p_0603 | R28, R37 |  |  |  |  |  |  | 5.1k 5% | 0.01 | 0.003 |  | 2 | TME | TME |  |  |  |  |  |  |  |  |  |  |  |  |  |  | 5.1k 5% | Bottom
6.8k | Resistor 0603 5% 0,1W | R32 | RES_0603 | RES_10k_5p_0603 | R32 |  |  |  |  |  |  | 6.8k | 0.01 | 0.003 |  | 1 |  |  |  |  |  |  |  |  |  |  |  |  |  |  |  |  | 10k 5% | Bottom
50k 10% | Pot 500mW wieloobrotowy | R33, R34 | RES_PV36 | RESV_50k_10p_THT | R33, R34 | SR PASSIVES | Loading... |  | T910W-50K | Loading... |  | 50k 10% | 0.3 | 0.2 |  | 2 | TME | TME |  | Loading... |  |  |  | T910W-50K | T910W-50K |  |  |  |  |  | Loading... |  | 50k 10% | Top
330R | Resistor 2W 5% THT | R38, R39 | RES_AXIAL2W | RES_330R_5p_2W | R38, R39 |  |  |  |  |  |  | 330R |  |  |  | 2 |  |  |  |  |  |  |  |  |  |  |  |  |  |  |  |  | 330R | Top
0R 5% | 0603 ,1W | R49, R50, R51, R54, R55, R56 | RES_0603 | RES_0R_5p_0603 | R49, R50, R51, R54, R55, R56 | YAGEO | Loading... |  | RC0603JR-070RL | Loading... |  | 0R 5% | 0.09 | 0.003 |  | 6 | TME | TME |  | Loading... |  |  |  | RC0603JR-070R | RC0603JR-070R |  |  |  |  |  | Loading... |  | 0R 5% | Bottom
1M | Resistor 0603 5% 0,1W | R61 | RES_0603 | RES_3k_5p_0603 | R61 | YAGEO | Loading... |  |  | Loading... |  | 1M | 0.01 | 0.003 |  | 1 | TME | TME |  | Loading... |  |  |  | SMD0603-3K | SMD0603-3K |  |  |  |  |  | Loading... |  | 3k 5% | Bottom
4.7k | Resistor 0603 5% 0,1W | R68, R69 | RES_0603 | RES_10k_5p_0603 | R68, R69 |  |  |  |  |  |  | 4.7k | 0.01 | 0.003 |  | 2 |  |  |  |  |  |  |  |  |  |  |  |  |  |  |  |  | 4.7k | Bottom
short | TERMISTOR, NTC, 4000K fi 6,5mm | RT1 | CON_PIN1x2_THT | REST_10k_10p_THT | RT1 | SR PASSIVES | Loading... |  | NTCC-10K | Loading... |  | short | 0.3 | 0.1 |  | 1 | TME | TME |  | Loading... |  |  |  | NTCC-10K | NTCC-10K |  |  |  |  |  | Loading... |  | 10k B=4000K | Top
10k B=4000K | TERMISTOR, NTC, 4000K fi 6,5mm | RT2, RT3 | CON_PIN1x2_THT | REST_10k_10p_THT | RT2, RT3 | SR PASSIVES | Loading... |  | NTCC-10K | Loading... |  | 10k B=4000K | 0.3 | 0.1 |  | 2 | TME | TME |  | Loading... |  |  |  | NTCC-10K | NTCC-10K |  |  |  |  |  | Loading... |  | 10k B=4000K | Top
650V | warystor S14 30VAC 38VDC 1kA 9J@2ms | RV1, RV2 | RES_VAR_S14 | RESV_38V_1kA_THT | RV1, RV2 | EPCOS | Loading... |  | B72214S0300K101 | Loading... |  | 650V | 0.83 | 0.38 |  | 2 | TME | TME |  | Loading... |  |  |  | SIOV-S14K30 | SIOV-S14K30 |  |  |  |  |  | Loading... |  | B72214S0300K101 30VAC 1kA | Top
SW_SPDTRA_THT |  | SW1 | SW_SPDT_RA | SW_SPDTRA_THT | SW1 |  | Supplier disabled |  |  | Supplier disabled |  | SW_SPDTRA_THT |  |  |  | 1 |  | aliexpress |  | Supplier disabled |  |  |  |  | https://pl.aliexpress.com/item/4000525611467.html?spm=a2g0s.9042311.0.0.7b675c0frz8uLg |  |  |  |  |  | $0.1402 |  |  | Top
SW_DPDTRA_SLIDE_THT |  | SW2 | SW_DPDT_SLIDE | SW_DPDTRA_SLIDE_THT | SW2 |  | Supplier disabled | Supplier disabled | SK22d02 | Supplier disabled | Supplier disabled | SW_DPDTRA_SLIDE_THT |  |  |  | 1 |  | aliexpress |  | Supplier disabled | Supplier disabled |  |  |  | https://pl.aliexpress.com/item/32872245827.html?spm=a2g17.12010612.8148356.9.48da3152dKCiYy | EG2208A |  |  |  |  | $0.1402 |  |  | Top
SI8261BCD-C-IS | 4.0 A ISOLATED GATE DRIVER 5kV Vdd6.5-30V | T1, T4 | SDPI6_SOICW6 | T_SI8261 | T1, T4 | SiLabs | Loading... (https://octopart-clicks.com/click/altium?sku=SI8261BCD-C-IS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) | Loading... (https://octopart-clicks.com/click/altium?sku=SI8261BCD-C-IS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) | SI8261BCD-C-IS | Loading... (https://octopart-clicks.com/click/altium?sku=SI8261BCD-C-IS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) | Loading... (https://octopart-clicks.com/click/altium?sku=SI8261BCD-C-IS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) | SI8261BCD-C-IS |  |  |  | 2 |  | TME | TME | Loading... | Loading... |  |  |  | SI8261BCD-C-IS (https://octopart-clicks.com/click/altium?sku=SI8261BCD-C-IS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) | SI8261BCD-C-IS (https://octopart-clicks.com/click/altium?sku=SI8261BCD-C-IS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) |  |  |  |  | Loading... |  |  | Bottom
C3M0065100K | SiC 1kV 35A N mosfet Rdson 0.07@UGS=15V Qg=35nC | T2, T3 | TO247-4 | T_C3M0065100K_THT | T2, T3 | CREE/wolfspeed | Loading... |  | C3M0065100K | Loading... |  | C3M0065100K | 16.5 | 13 |  | 2 | TME | Farnell |  | Loading... |  |  |  | C3M0065100K | 2672013 |  |  |  |  |  | Loading... |  | C3M0065100K | Top
TLP181 | transoptor CTR Blank 50 600 Blank ,Y■,YE,G,G■,GR,B,BL,GB Rank Y 50 150 YE, Y■ Rank GR 100 300 GR, G, G■ Rank BL 200 600 BL, B Rank GB 100 600 GB , GR , G, G■, BL , B Rank YH 75 150 Y■ Rank GRL 100 200 G Rank GRH 150 300 G■ Rank BLL 200 400 B If 50mA Ic50mA ICE0 0,1uA@10V | T5, T6, T7, T8, T9, T10 | TOSH-11-4C1_N | T_TLP181 | T5, T6, T7, T8, T9, T10 |  |  |  |  |  |  | TLP181 |  |  |  | 6 |  |  |  |  |  |  |  |  |  |  |  |  |  |  |  |  |  | Bottom
Value | -60V -2.9A 2x P MOSFET, 135/105mR | T11 | SOIC8M | T_FDS9958 | T11 | ON Semiconductor / Fairchild | Loading... (https://octopart-clicks.com/click/altium?sku=FDS9958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) | Loading... (https://octopart-clicks.com/click/altium?sku=FDS9958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) | FDS9958 | Loading... (https://octopart-clicks.com/click/altium?sku=FDS9958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) | Loading... (https://octopart-clicks.com/click/altium?sku=FDS9958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) | Value |  |  |  | 1 | FARNELL | Digi-Key | TME | Loading... | Loading... |  |  | 1471052RL | FDS9958CT-ND (https://octopart-clicks.com/click/altium?sku=FDS9958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) | FDS9958 (https://octopart-clicks.com/click/altium?sku=FDS9958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) |  |  |  |  | $0.95 |  |  | Bottom
N mosfet BSS138 | 50V 0.3A N mosfet Rdson 6ohm @UGS=4.5V Qg=2.5nC | T12, T13 | SOT23-3 | T_BSS138 | T12, T13 | FAIRCHILD | Loading... |  | BSS138 | Loading... |  | N mosfet BSS138 | 0.22 | 0.04 |  | 2 | TME | Farnell |  | Loading... |  |  |  | BSS138 | 2323154 |  |  |  |  |  | Loading... |  | N mosfet BSS138 | Bottom
AM1D-1209DH30Z | SMPS converter +9V and -9V, 1W, 3kV iso | U1, U6 | MOD_AIMTEC_AM1D-Z | MOD_AM1D-1209DH30Z_THT | U1, U6 | AIMTEC | Loading... |  | AM1D-1209DH30Z | Loading... |  | AM1D-1209DH30Z | 6 | 5 |  | 2 | TME | TME |  | Loading... |  |  |  | AM1D-1209DH30Z | AM1D-1209DH30Z |  |  |  |  |  | Loading... |  | AM1D-1209DH30Z | Top
IXDN609SI | single 9A High-speed low side gate driver | U2, U3 | SOIC8M_PP | IC_IXDN609SI | U2, U3 | IXYS | Loading... (https://octopart-clicks.com/click/altium?sku=IXDN609SI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) | Loading... (https://octopart-clicks.com/click/altium?sku=IXDN609SI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) | IXDN609SI | Loading... (https://octopart-clicks.com/click/altium?sku=IXDN609SI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) | Loading... (https://octopart-clicks.com/click/altium?sku=IXDN609SI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) | IXDN609SI |  |  | 1=1.81, 10=1.3 (USD) | 2 |  | TME | TME | Loading... | Loading... |  |  |  | IXDN609SI (https://octopart-clicks.com/click/altium?sku=IXDN609SI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) | IXDN609SI (https://octopart-clicks.com/click/altium?sku=IXDN609SI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) |  |  |  |  | Loading... |  |  | Bottom
LM224NG | LM224_324_2902_NCV2902-14 | U4 | DIP14 | IC_LM224 | U4 | ON SEMICONDUCTOR | Loading... |  | LM224NG | Loading... |  | LM224NG |  |  | 5=0.3313, 25=0.2966, 100=0.2409, 250=0.2051, 1000=0.1832 (USD) | 1 |  | TME |  | Loading... |  |  |  |  | LM224NG |  |  |  |  |  | Loading... |  |  | Top
RAC05-12SK/480 RECOM | SMPS 10W 12V 800mA, 430V DC in | U5 | MOD_RAC10-12SK/277 | MOD_RAC10-12SK/277_THT | U5 | RECOM | Loading... |  | RAC05-12SK/480 RECOM | Loading... |  | RAC05-12SK/480 RECOM | 10 | 8 |  | 1 | TME | TME |  | Loading... |  |  |  | RAC05-12SK/480 RECOM | RAC05-12SK/480 RECOM |  |  |  |  |  | Loading... |  | RAC05-12SK/480 RECOM | Top

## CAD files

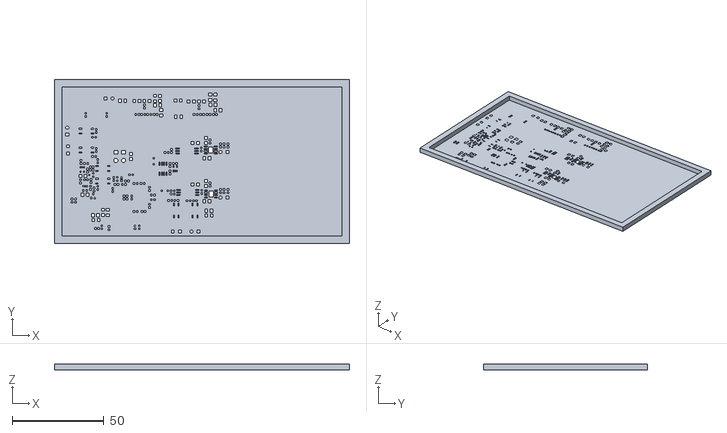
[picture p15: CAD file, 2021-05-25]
Mech/PVPWM_Heater_v2 v1.stl
160.5 x 89.3 x 3.00

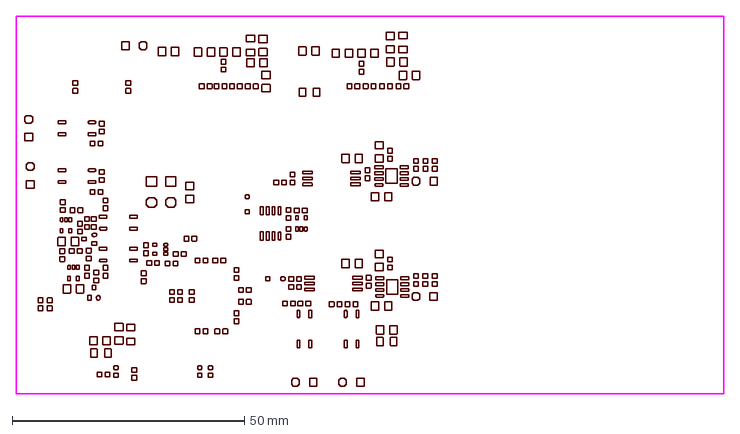
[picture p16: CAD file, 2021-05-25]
Mech/PV_PWM_heater_v2_4.DXF
152.2 x 81.3 mm

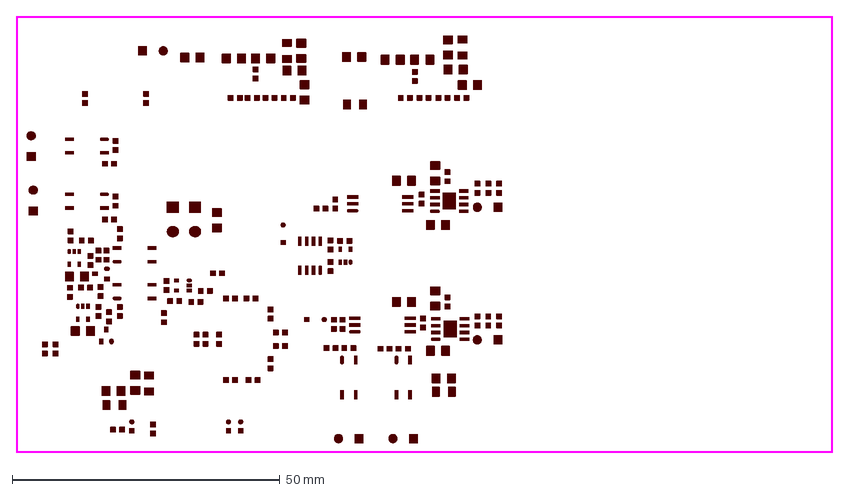
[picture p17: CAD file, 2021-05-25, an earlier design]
Mech/PV_PWM_heater_v2.DXF
152.5 x 81.5 mm

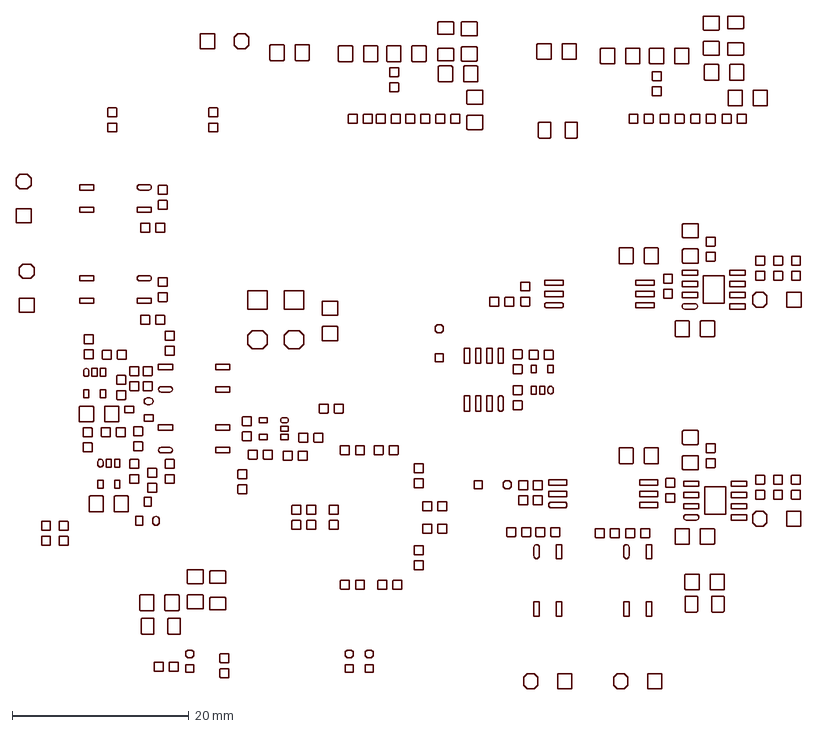
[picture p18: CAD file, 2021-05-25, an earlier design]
Mech/PV_PWM_heater_v2_3.DXF
88.8 x 76.1 mm

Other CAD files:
Mech/PV_PWM_heater_v2_BP.DWG
Mech/PVPWM_Heater_v2 v1.f3d

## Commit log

2021-05-25 working version
    [Bill of Materials-PV_PWM_heater_v2.xlsx, PVPWM_Heater_v2 v1.f3d, PVPWM_Heater_v2 v1.stl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]
2021-05-25 diagrams added
    [Schematic diagram.SchDoc]
